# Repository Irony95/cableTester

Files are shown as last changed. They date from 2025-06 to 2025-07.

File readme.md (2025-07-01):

### Bill Of Materials
1. 1x all printed parts (9v-BatteryBracket.stl and 9v-BatteryCover.stl excluded)
2. 1x 16-26 (Baseband Connector)
3. 1x 14-1m9 (Data Connector)
4. 7x Eth 5e keystone connector
5. 1x RS232 Male port
6. 10x M3*5 Heat set inserts
7. 10x M3 Nut
8. 20x M3*6 Socket cap screw
9. 1x M3*6 screw ball plunger
10. 1x 3 AA battery Holder
11. Custom PCB
12. Multistrand wire (For port connection)
13. 3x JST-XH 8P Vertical Male connector + female wire
14. 1x JST-XH 2P vertical Male Connector + female wire
15. 8x 0805 330Ω resistor
16. 1x SK12D07 3-pin toggle switch
17. 1x 1*14P 2.54mm Straight female header
18. 1x Raspberry Pi Pico
19. 1x ili9341 Display

#### Note for old version of PCB
resistors R9 to R16 should not be soldered, and VBUS should be shorted to VSYS.
Avoid powering the circuit while plugged into USB.
These issues are fixed for latest PCB.

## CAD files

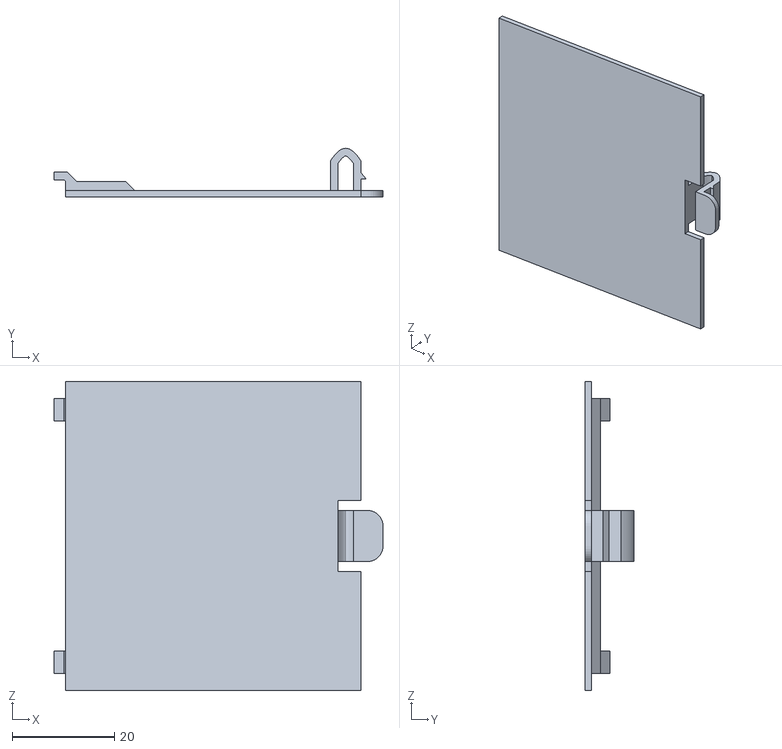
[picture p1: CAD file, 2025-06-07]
3D model/stls/9V-attachment/9v-BatteryCover.stl
64.4 x 9.50 x 60.5

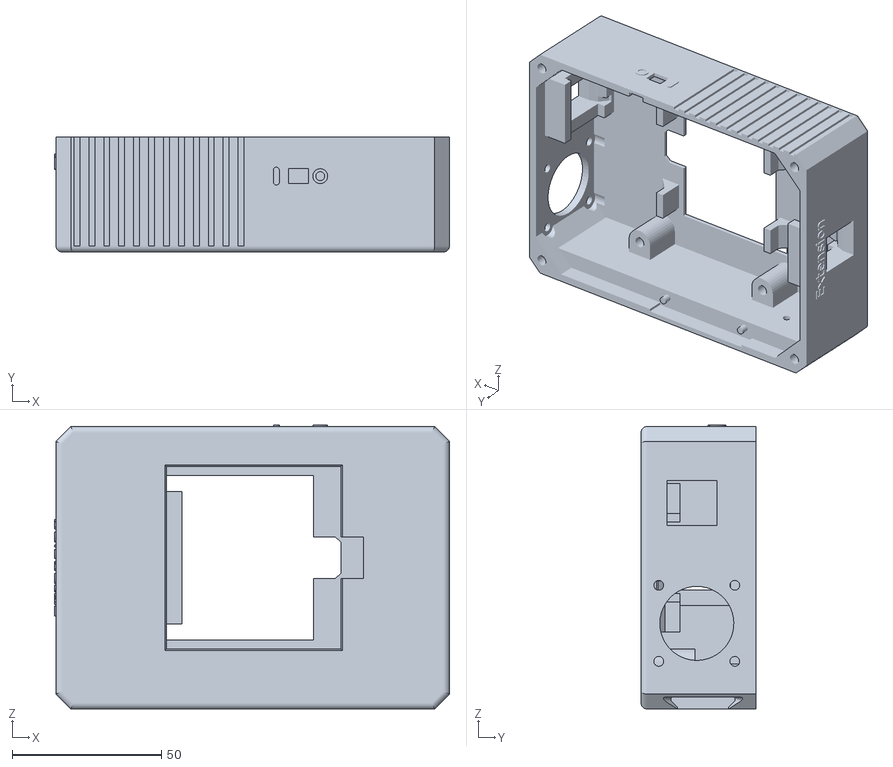
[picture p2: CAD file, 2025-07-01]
3D model/stls/CaseBody.stl
132.3 x 38.5 x 95.1

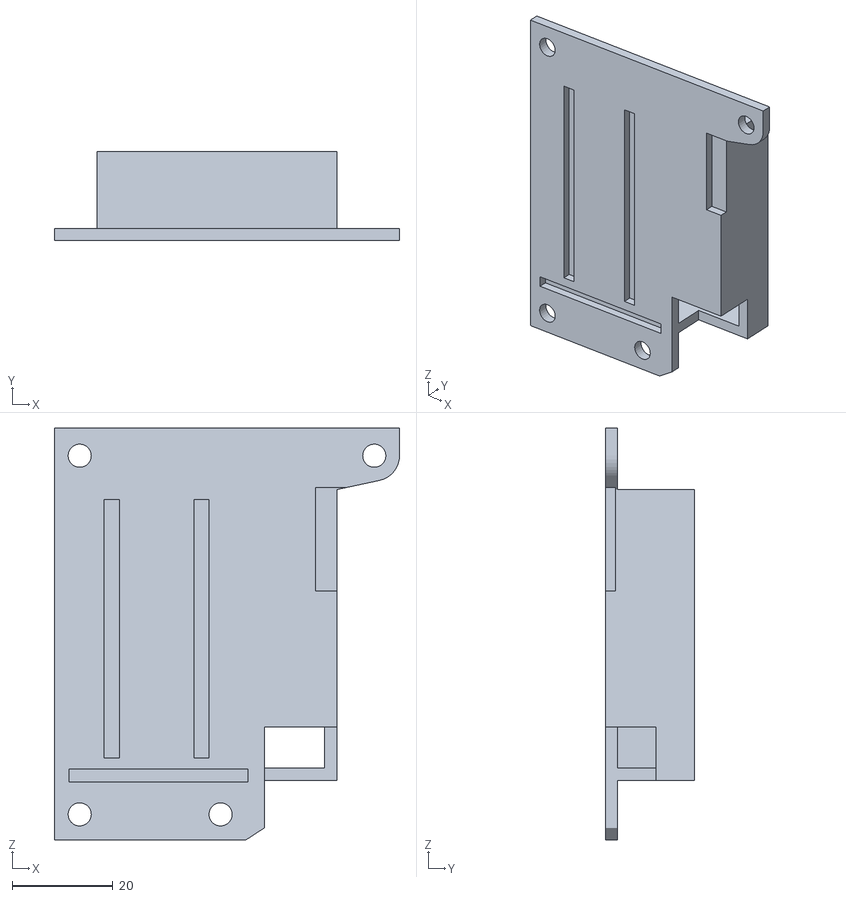
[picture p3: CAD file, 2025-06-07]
3D model/stls/9V-attachment/9v-BatteryBracket.stl
68.4 x 17.7 x 81.7

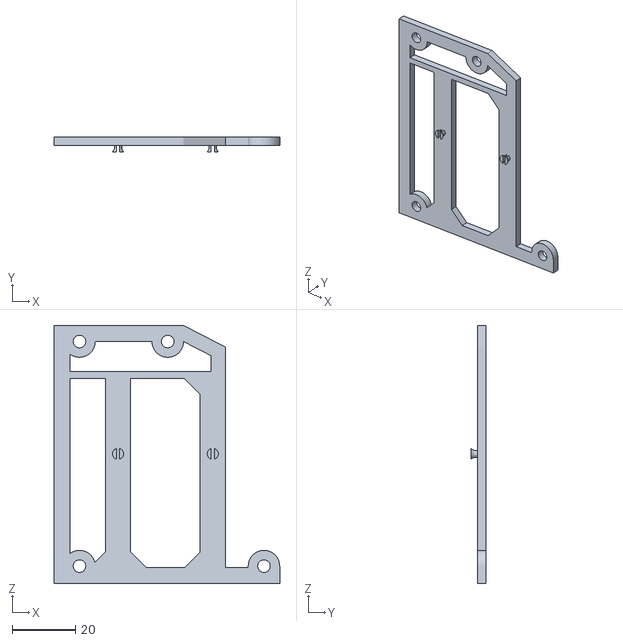
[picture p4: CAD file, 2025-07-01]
3D model/stls/BatteryBracket.stl
71.4 x 4.80 x 81.7

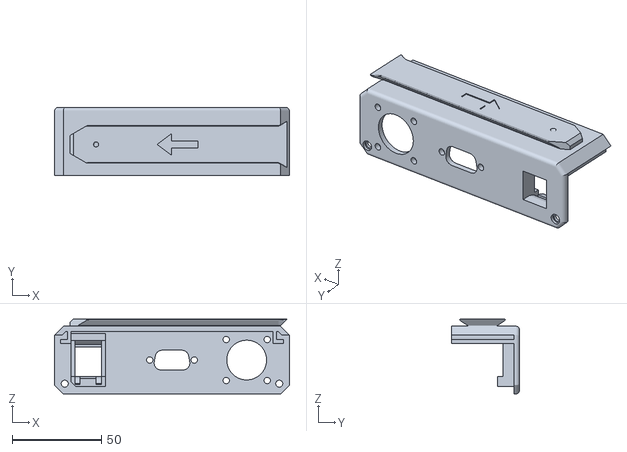
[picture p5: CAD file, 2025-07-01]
3D model/stls/DongleLid.stl
131.8 x 38.2 x 42.0

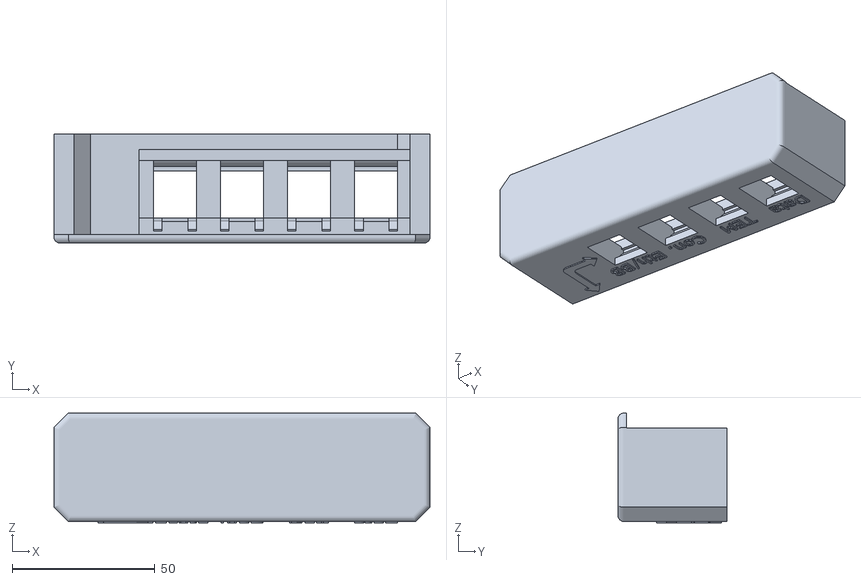
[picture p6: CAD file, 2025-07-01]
3D model/stls/DongleBody.stl
131.8 x 38.2 x 38.5

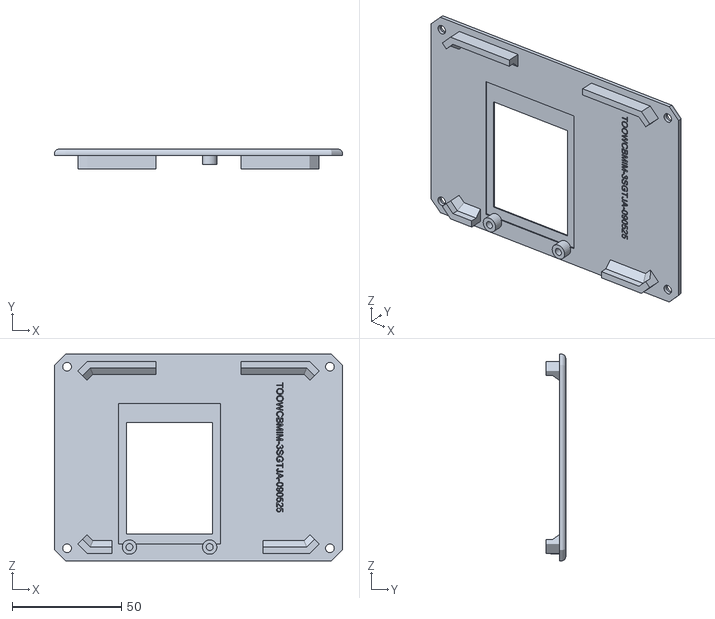
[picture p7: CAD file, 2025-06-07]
3D model/stls/CaseLid.stl
131.8 x 9.00 x 94.6

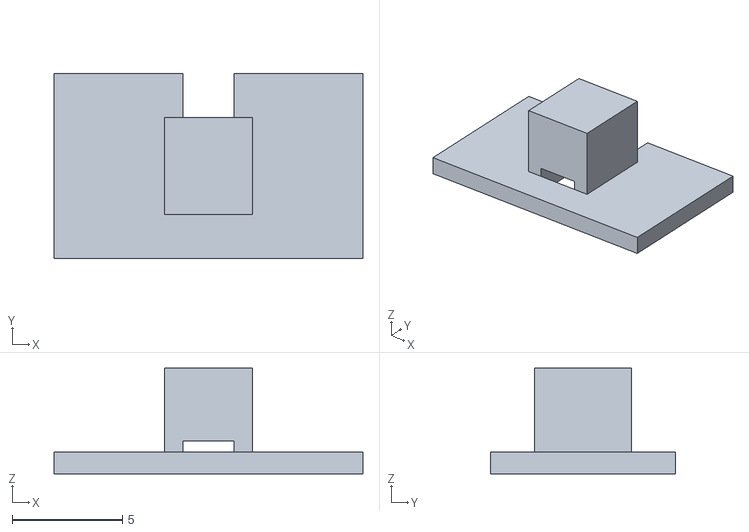
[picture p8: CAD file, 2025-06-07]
3D model/stls/Switch.stl
14.0 x 8.40 x 4.80

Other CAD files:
3D model/stls/BatteryCover.stl
3D model/CableTester v43.f3z

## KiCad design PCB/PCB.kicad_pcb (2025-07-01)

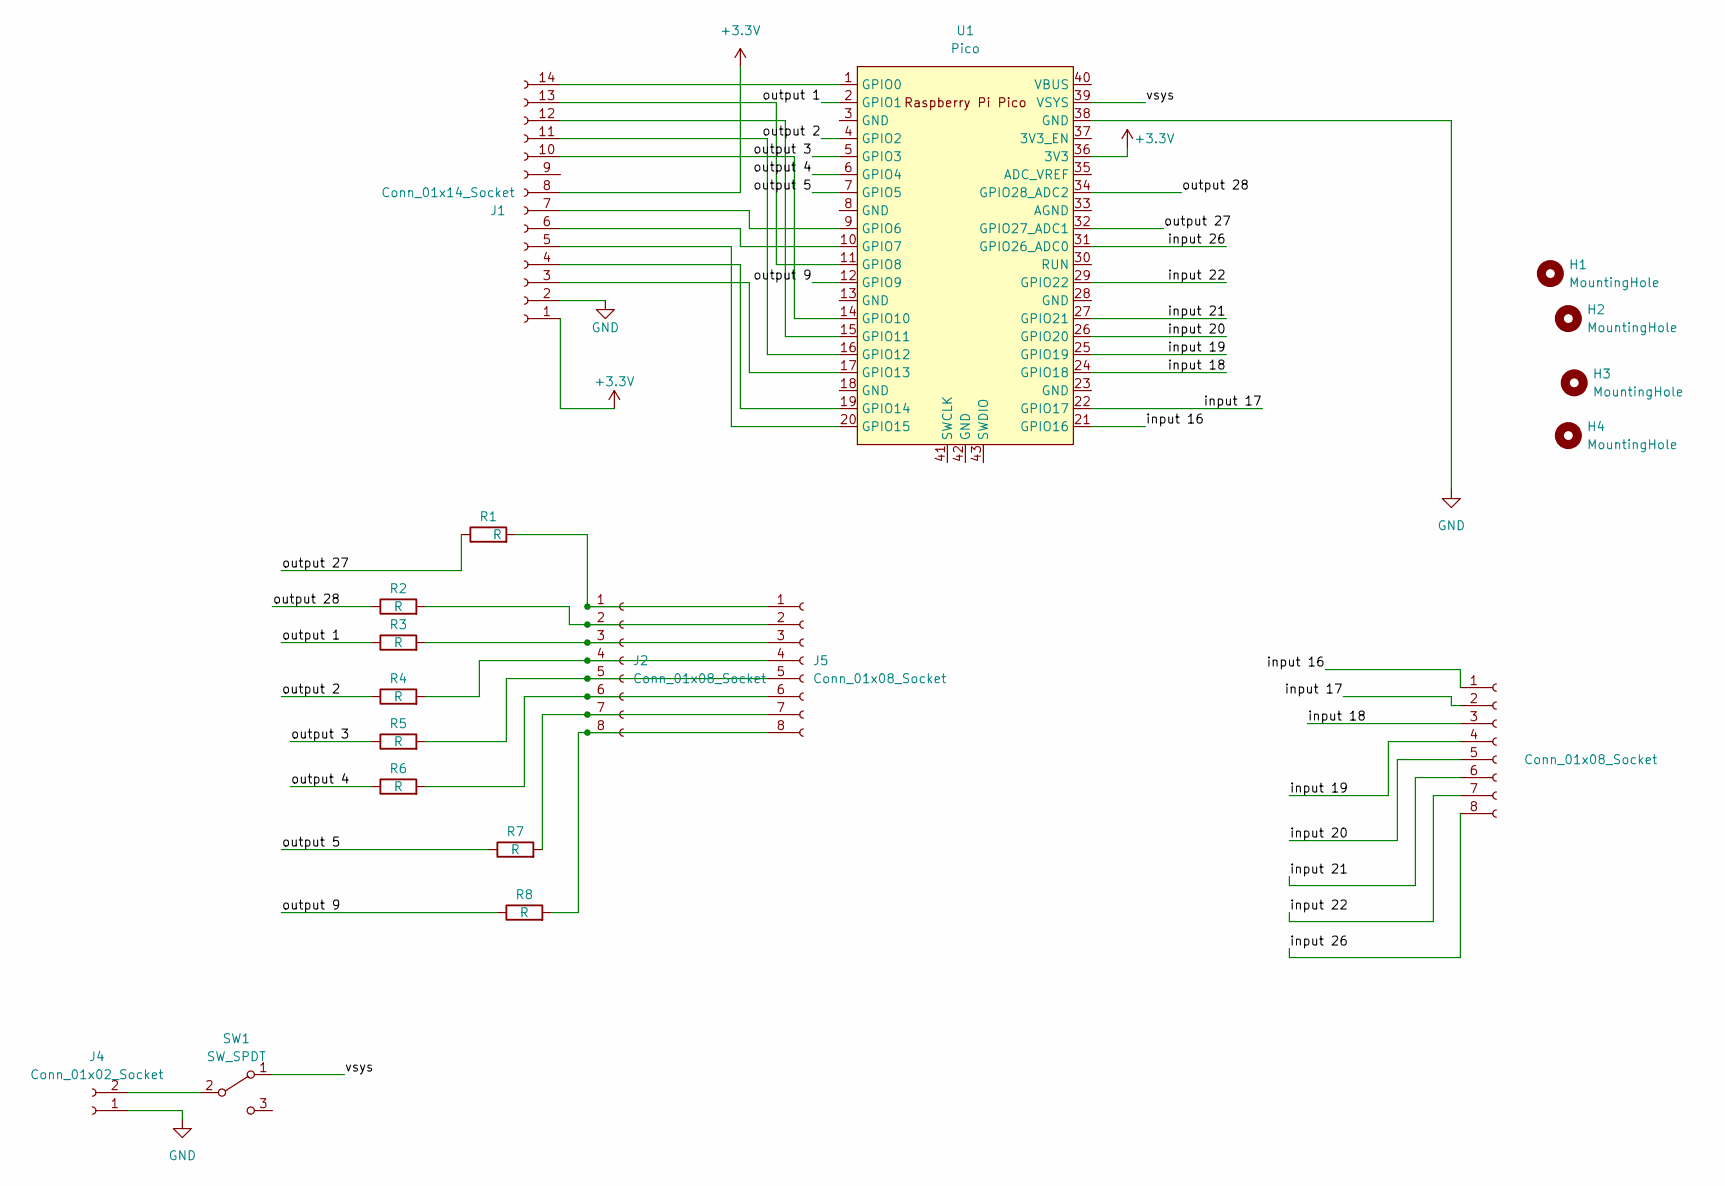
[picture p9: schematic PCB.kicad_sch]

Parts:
H1, H2, H3, H4: MountingHole; MountingHole_3.2mm_M3_Pad_TopBottom
J1: Conn_01x14_Socket; PinSocket_1x14_P2.54mm_Vertical
J2, J3, J5: Conn_01x08_Socket; JST_XH_B8B-XH-AM_1x08_P2.50mm_Vertical
J4: Conn_01x02_Socket; JST_XH_B2B-XH-AM_1x02_P2.50mm_Vertical
R1, R2, R3, R4, R5, R6, R7, R8: R; R_0805_2012Metric
SW1: SW_SPDT; SW_Slide_1P2T_CK_OS102011MS2Q
U1: Pico; RPi_Pico_SMD_TH

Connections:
+3.3V: J1.1, J1.8, U1.36 (3V3)
/input 16: J3.1, U1.21 (GPIO16)
/input 17: J3.2, U1.22 (GPIO17)
/input 18: J3.3, U1.24 (GPIO18)
/input 19: J3.4, U1.25 (GPIO19)
/input 20: J3.5, U1.26 (GPIO20)
/input 21: J3.6, U1.27 (GPIO21)
/input 22: J3.7, U1.29 (GPIO22)
/input 26: J3.8, U1.31 (GPIO26_ADC0)
/output 1: R3.1, U1.2 (GPIO1)
/output 2: R4.1, U1.4 (GPIO2)
/output 3: R5.1, U1.5 (GPIO3)
/output 4: R6.1, U1.6 (GPIO4)
/output 5: R7.1, U1.7 (GPIO5)
/output 9: R8.1, U1.12 (GPIO9)
/output 27: R1.1, U1.32 (GPIO27_ADC1)
/output 28: R2.1, U1.34 (GPIO28_ADC2)
/vsys: SW1.1 (A), U1.39 (VSYS)
GND: J1.2, J4.1, U1.38 (GND)
unnamed: J1.3, U1.17 (GPIO13)
unnamed: J1.4, U1.19 (GPIO14)
unnamed: J1.5, U1.20 (GPIO15)
unnamed: J1.6, U1.10 (GPIO7)
unnamed: J1.7, U1.9 (GPIO6)
unnamed: J1.10, U1.14 (GPIO10)
unnamed: J1.11, U1.16 (GPIO12)
unnamed: J1.12, U1.15 (GPIO11)
unnamed: J1.13, U1.11 (GPIO8)
unnamed: J1.14, U1.1 (GPIO0)
unnamed: J2.1, J5.1, R1.2
unnamed: J2.2, J5.2, R2.2
unnamed: J2.3, J5.3, R3.2
unnamed: J2.4, J5.4, R4.2
unnamed: J2.5, J5.5, R5.2
unnamed: J2.6, J5.6, R6.2
unnamed: J2.7, J5.7, R7.2
unnamed: J2.8, J5.8, R8.2
unnamed: J4.2, SW1.2 (B)

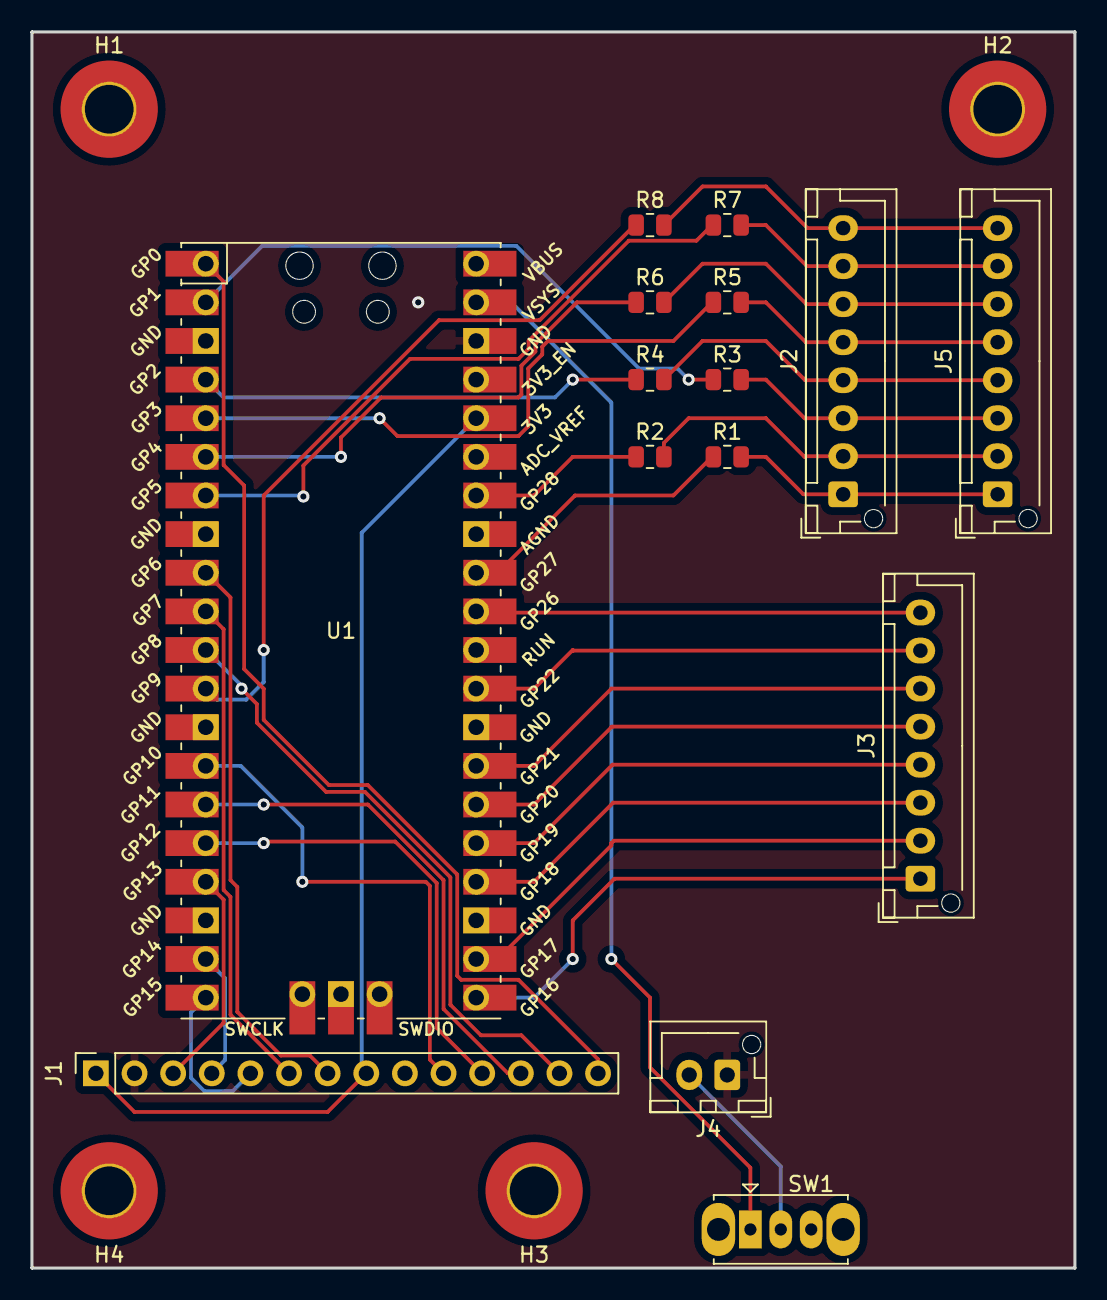
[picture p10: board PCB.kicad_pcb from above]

Board: 2 copper layers, 68.6 x 81.3 mm, 19 parts (0 on the bottom side), 38 nets.

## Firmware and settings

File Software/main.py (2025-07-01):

import mySetupX
from time import sleep_ms
import sys


if __name__ == "__main__":
    display = mySetupX.createMyDisplay()
    display.clear()
    display.draw_image("6AMB.raw", w=320)

    from pages import pages

    def button_checker(x, y):
        print(f"touch detected at {(x, y)}")
        global lock
        if not lock:
            global display
            global page
            global refresh
            global args
            global is_first_run
            for btn in pages[page].BUTTONS:
                if btn.is_in_region(x, y):
                    task, args = btn.run(x, y)
                    args = args
                    if task is not None:
                        page = task
                        page_obj = pages[page]
                        refresh = getattr(page_obj, "REFRESH", False)
                        is_first_run = True

    page = "home_page"
    args = ()
    refresh = False
    lock = False
    is_first_run = True

    sleep_duration = 0.02
    sleep_duration_ms = int(sleep_duration * 1000)
    polling_rate = int(1 / sleep_duration)
    refresh_rate = 2
    sleeps_per_sec = polling_rate * refresh_rate

    xptTouch = mySetupX.createXPT(button_checker)

    while True:
        try:
            if not lock and is_first_run:
                lock = True
                display.clear()
                pages[page].main(display, *args)
                is_first_run = False
                lock = False
            if refresh and not is_first_run:
                for _ in range(sleeps_per_sec):
                    if refresh and not is_first_run:
                        sleep_ms(sleep_duration_ms)
                    else:
                        break
                else:
                    if refresh and not is_first_run:
                        lock = True
                        pages[page].main(display, *args)
                        lock = False
        except KeyboardInterrupt:
            print("shutting down...")
            sys.exit(0)

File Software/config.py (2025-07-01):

from machine import Pin
from xglcd_font import XglcdFont


FONT = XglcdFont("Unispace12x24.c", 12, 24)
PIN_IN_MAP = {  # read value
    0: Pin(16, Pin.IN, Pin.PULL_DOWN),
    1: Pin(17, Pin.IN, Pin.PULL_DOWN),
    2: Pin(18, Pin.IN, Pin.PULL_DOWN),
    3: Pin(19, Pin.IN, Pin.PULL_DOWN),
    4: Pin(20, Pin.IN, Pin.PULL_DOWN),
    5: Pin(21, Pin.IN, Pin.PULL_DOWN),
    6: Pin(22, Pin.IN, Pin.PULL_DOWN),
    7: Pin(26, Pin.IN, Pin.PULL_DOWN),
}
PIN_OUT_MAP = {  # set value
    0: Pin(27, Pin.OUT),
    1: Pin(28, Pin.OUT),
    2: Pin(1, Pin.OUT),
    3: Pin(2, Pin.OUT),
    4: Pin(3, Pin.OUT),
    5: Pin(4, Pin.OUT),
    6: Pin(5, Pin.OUT),
    7: Pin(9, Pin.OUT),
}
TEST_PROFILES = [
    {
        "label": "BB > ETH",
        "out_to_in_pin_map": {  # out : in
            0: (0,),
            1: (1,),
            2: (),
            3: (),
            4: (),
            5: (5,),
            6: (),
            7: (),
        },
        "cable_pin_map": {
            0: (("G",), ("1",)),
            1: (("H",), ("2",)),
            2: (),
            3: (),
            4: (),
            5: (("R",), ("6",)),
            6: (),
            7: (),
        },
    },
    {
        "label": "ETH > RS232",
        "out_to_in_pin_map": {  # out : in
            0: (0,),
            1: (1,),
            2: (2,),
            3: (3,),
            4: (4,),
            5: (5,),
            6: (6,),
            7: (7,),
        },
        "cable_pin_map": {
            0: (("1",), ("8",)),
            1: (("2",), ("2",)),
            2: (("3",), ("3",)),
            3: (("4",), ("1",)),
            4: (("5",), ("5",)),
            5: (("6",), ("4",)),
            6: (("7",), ("9",)),
            7: (("8",), ("7",)),
        },
    },
    {
        "label": "ETH > DATA",
        "out_to_in_pin_map": {  # out : in
            0: (0,),
            1: (1, 4, 5, 7),
            2: (2,),
            3: (3,),
            4: (1, 4, 5, 7),
            5: (1, 4, 5, 7),
            6: (6,),
            7: (1, 4, 5, 7),
        },
        "cable_pin_map": {
            0: (("1",), ("D")),
            1: (("2",), ("M", "N", "H")),
            2: (("3",), ("C",)),
            3: (("4",), ("J",)),
            4: (("5",), ("M", "N", "H")),
            5: (("6",), ("M", "N", "H")),
            6: (("7",), ("R",)),
            7: (("8",), ("M", "N", "H")),
        },
    },
    {
        "label": "BB > TEM",
        "out_to_in_pin_map": {  # out : in
            0: (0,),
            1: (1,),
            2: (2,),
            3: (3,),
            4: (4,),
            5: (5,),
            6: (6,),
            7: (7,),
        },
        "cable_pin_map": {
            0: (("L",), ("E",)),
            1: (("M",), ("F",)),
            2: (("D",), ("G",)),
            3: (("E",), ("H",)),
            4: (("J",), ("J",)),
            5: (("K",), ("K",)),
            6: (("U",), ("L",)),
            7: (("V",), ("M",)),
        },
    },
    {
        "label": "Straight ETH",
        "out_to_in_pin_map": {  # out : in
            0: (0,),
            1: (1,),
            2: (2,),
            3: (3,),
            4: (4,),
            5: (5,),
            6: (6,),
            7: (7,),
        },
        "cable_pin_map": {
            0: (("1",), ("1",)),
            1: (("2",), ("2",)),
            2: (("3",), ("3",)),
            3: (("4",), ("4",)),
            4: (("5",), ("5",)),
            5: (("6",), ("6",)),
            6: (("7",), ("7",)),
            7: (("8",), ("8",)),
        },
    },
]

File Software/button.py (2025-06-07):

from ili9341 import color565
import mySetupX
from config import FONT
from tools import fill_super_ellipse


class button:
    def __init__(
        self,
        x,
        y,
        w,
        h,
        text=None,
        font_colour=None,
        colour=None,
        region=None,
        task=None,
        task_args=(),
    ) -> None:
        self.x = x
        self.y = y
        self.w = w
        self.h = h
        self.text = text
        self.font_colour = font_colour
        self.region = region
        self.colour = colour
        self.font = FONT
        self.task = task
        self.task_args = task_args

        if self.text is not None:
            if self.h < 24:
                raise ValueError("Button not tall enough for text")
            if self.w < 12 * len(self.text):
                raise ValueError("Button not wide enough for text")
        if self.font_colour is None:
            self.font_colour = color565(0, 0, 0)
        if colour is None:
            self.colour = color565(0, 255, 0)
        if region is None:
            self.region = {"x_min": x, "x_max": x + w, "y_min": y, "y_max": y + h}

    def draw(self, display):
        fill_super_ellipse(display, self.x, self.y, self.w, self.h, self.colour)
        if self.text is not None:
            text_x = round((self.w - 12 * len(self.text)) / 2 + self.x)
            text_y = round((self.h - 24) / 2 + self.y)
            display.draw_text(
                text_x,
                text_y,
                self.text,
                self.font,
                color=self.font_colour,
                background=self.colour,
            )

    def is_in_region(self, x, y):
        x_min = self.region["x_min"]
        x_max = self.region["x_max"]
        y_min = self.region["y_min"]
        y_max = self.region["y_max"]
        return (x_min <= x <= x_max) and (y_min <= y <= y_max)

    def run(self, x, y):
        print(f"hello! I am button ({self.x}, {self.y})")
        return self.task, self.task_args


def button_checker(x, y):
    global buttons
    [btn.run(btn.x, btn.y) for btn in buttons if btn.is_in_region(x, y)]


if __name__ == "__main__":
    display = mySetupX.createMyDisplay()
    display.clear()
    xptTouch = mySetupX.createXPT(button_checker)
    buttons = [
        button(
            8,
            58 * i + 8,
            200,
            50,
            text=f"btn {i}",
            font_colour=color565(0, 0, 0),
        )
        for i in range(4)
    ]

    while True:
        try:
            pass
        except KeyboardInterrupt:
            print("shutting down...")

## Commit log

2025-04-14 Created buttons!
2025-04-15 Test draw image and text in buttons
2025-04-16 added main page and cable testing
2025-05-09 1) rewrote event loop in main.py 2) moved display.clear() to main event loop 3) add lock "mutex" to prevent race condition
    [details_page.py, home_page.py, main.py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]
2025-06-04 button aesthetics
2025-06-07 introduced (probably) finalized 3d model and PCB, along with reorganizing folders
    [BatteryBracket.stl, BatteryCover.stl, CableTester v36.f3z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]
2025-06-07 created bill of materials
    [PCB.csv, PCB.kicad_pcb, PCB.kicad_sch]
2025-06-07 Updated BOM
2025-06-12 updated to use internal pull down resistors, remove them from PCB design
    [PCB-B_Cu.gbr, PCB-B_Mask.gbr, PCB-B_Paste.gbr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]
2025-06-14 3D model changes, added ETH passthrough and remodelled AA battery bracket
    [9v-BatteryBracket.stl, 9v-BatteryCover.stl, BatteryBracket.stl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]
2025-07-01 1) print touch x, y to console 2) tweaked touch X and Y min max 3) added an intermediary page, diagram_page. it's current purpose is as a dummy page for when "Test" button is not yet pressed. this is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
2025-07-07 add small delay after turning on or off a pin
